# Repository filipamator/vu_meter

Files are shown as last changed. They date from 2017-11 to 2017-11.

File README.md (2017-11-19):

# vu_meter

This is a simple FPGA-based FFT audio signal analyzer. 
The project was made using Intel-Altera Quartus Prime 16.1 and implemented on DE2-115 board from Terasic.

I used an IP Core generated by Spiral Project, Carnegie Mellon University (http://www.spiral.net/hardware/dftgen.html).
The project is mostly written in VHDL with small exceptions  (SystemVerilog for ILI9341 TFT display, Verilog for I2S audio chip).

What does it do?
- An audio sample (1024 16-bit words from the left channel) is acquired using on-board I2S chip with 48 kHz (50 kHz in fact) sampling rate and 24 bits of vertical resolution. Only MSB 16 bits are used for calculations.
- A Hanning window function is applied to the samples stored in the on-chip memory. Integer samples are converted into the IEE-754 format, multiplied with a proper coefficient  and then converted again into a integer format.
- Spectrum is calculated using DFT IP Core from Spiral project with a spectral resolution around 25kHz/511 = 48.9 Hz per point/bin.
- A log10 is calculated for every spectral point after conversion to IEE-754 floating point format; here values are scaled to fit into TFT display: a full-scale sine wave from ADC will be plotted as 240-pixel vertical line at 320x240 TFT display.
- A proper bitmap is generated and stored in the frame buffer.

Comments on hardware:
- The input audio signal is echoed to headphone output
- KEY(0) is a global reset signal. Use it after uploading a compiled design.
- SW(1) selects log or linear scale. 
- Pressing KEY(1) will dump data over on-board UART

IMAGE ALT TEXT HERE (https://www.youtube.com/watch?v=xRw6NkzDQ_o)

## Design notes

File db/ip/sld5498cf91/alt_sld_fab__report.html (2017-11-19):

alt_sld_fab

2017.11.18.16:18:49 | Datasheet

Overview

Memory Map

## alt_sld_fab

alt_sld_fab v16.1

Parameters

DESIGN_HASH | 08e7e7f25aea91c42cac
NODE_COUNT | 1
MAX_WIDTH | 33
SETTINGS | {fabric sld dir agent mfr_code 110 type_code 0 version 6 instance 0 ir_width 10 psig 9b67919e}
CLOCKS | {id {} }
AGENTS
EP_INFOS | {hpath {sld_signaltap:auto_signaltap_0} }
MIRROR | 0
TOP_HUB | 1
COMPOSED_SETTINGS | {fabric sld dir agent mfr_code 110 type_code 0 version 6 instance 0 ir_width 10 bridge_agent 0 prefer_host {} }
DEVICE_FAMILY | CYCLONEIVE
AUTO_DEVICE | Unknown
AUTO_DEVICE_SPEEDGRADE | Unknown
deviceFamily | UNKNOWN
generateLegacySim | false

Software Assignments
(none)

## alt_sld_fab_presplit

altera_super_splitter v16.1

Parameters

MAX_WIDTH | 33
SEND_WIDTHS | 12
RECEIVE_WIDTHS | 33
deviceFamily | UNKNOWN
generateLegacySim | false

Software Assignments
(none)

## alt_sld_fab_splitter

altera_sld_splitter v16.1

alt_sld_fab_presplit | pass | alt_sld_fab_splitter
| nodes
alt_sld_fab_sldfabric | clock_0
| clock_0
| node_0
| node_0

Parameters

FRAGMENTS

{{name clock type clock dir end ports { {tck clk in 1 0} } } {name node type conduit dir end ports { {tms tms in 1 1} {tdi tdi in 1 2} {tdo tdo out 1 0} {ena ena in 1 3} {usr1 usr1 in 1 4} {clr clr in 1 5} {clrn clrn in 1 6} {jtag_state_tlr jtag_state_tlr in 1 7} {jtag_state_rti jtag_state_rti in 1 8} {jtag_state_sdrs jtag_state_sdrs in 1 9} {jtag_state_cdr jtag_state_cdr in 1 10} {jtag_state_sdr jtag_state_sdr in 1 11} {jtag_state_e1dr jtag_state_e1dr in 1 12} {jtag_state_pdr jtag_state_pdr in 1 13} {jtag_state_e2dr jtag_state_e2dr in 1 14} {jtag_state_udr jtag_state_udr in 1 15} {jtag_state_sirs jtag_state_sirs in 1 16} {jtag_state_cir jtag_state_cir in 1 17} {jtag_state_sir jtag_state_sir in 1 18} {jtag_state_e1ir jtag_state_e1ir in 1 19} {jtag_state_pir jtag_state_pir in 1 20} {jtag_state_e2ir jtag_state_e2ir in 1 21} {jtag_state_uir jtag_state_uir in 1 22} {ir_in ir_in in 10 23} {irq irq out 1 1} {ir_out ir_out out 10 2} } clock clock assign {debug.controlledBy {link_0} } moduleassign {debug.virtualInterface.link_0 {debug.endpointLink {fabric sld index 1} } } } }
EXAMPLE
ADD_INTERFACE_ASGN | 0
deviceFamily | UNKNOWN
generateLegacySim | false

Software Assignments
(none)

## alt_sld_fab_jtagpins

altera_jtag_pins_bridge v16.1

Parameters

deviceFamily | UNKNOWN
generateLegacySim | false

Software Assignments
(none)

## alt_sld_fab_sldfabric

altera_sld_jtag_hub v16.1

alt_sld_fab_jtagpins | clock | alt_sld_fab_sldfabric
| clock
| node
| node
| | | clock_0 | alt_sld_fab_splitter
| | | clock_0
| | | node_0
| | | node_0
| | | ident | alt_sld_fab_ident
| | | ident_0

Parameters

DEVICE_FAMILY | CYCLONEIVE
SETTINGS | {mfr_code 110 type_code 0 version 6 instance 0 ir_width 10 bridge_agent 0 prefer_host {} }
COUNT | 1
N_SEL_BITS | 1
N_NODE_IR_BITS | 10
NODE_INFO | 00110000000000000110111000000000
COMPILATION_MODE | 0
BROADCAST_FEATURE | 0
FORCE_IR_CAPTURE_FEATURE | 1
FORCE_PRE_1_4_FEATURE | 0
NEGEDGE_TDO_LATCH | 1
ENABLE_SOFT_CORE_CONTROLLER | 0
TOP_HUB | 1
CONN_INDEX | 0
deviceFamily | UNKNOWN
generateLegacySim | false

Software Assignments
(none)

## alt_sld_fab_ident

altera_connection_identification_hub v16.1

alt_sld_fab_sldfabric | ident | alt_sld_fab_ident
| ident_0

Parameters

DESIGN_HASH | 08e7e7f25aea91c42cac
COUNT | 1
SETTINGS | {width 4 latency 0}
deviceFamily | UNKNOWN
generateLegacySim | false

Software Assignments
(none)

generation took 0,01 seconds | rendering took 0,03 seconds

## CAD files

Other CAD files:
db/stp1_auto_stripped.stp
stp1_auto_stripped.stp
stp1.stp

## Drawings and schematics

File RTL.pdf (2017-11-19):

Date: November 19, 2017 | Project: vu_meter

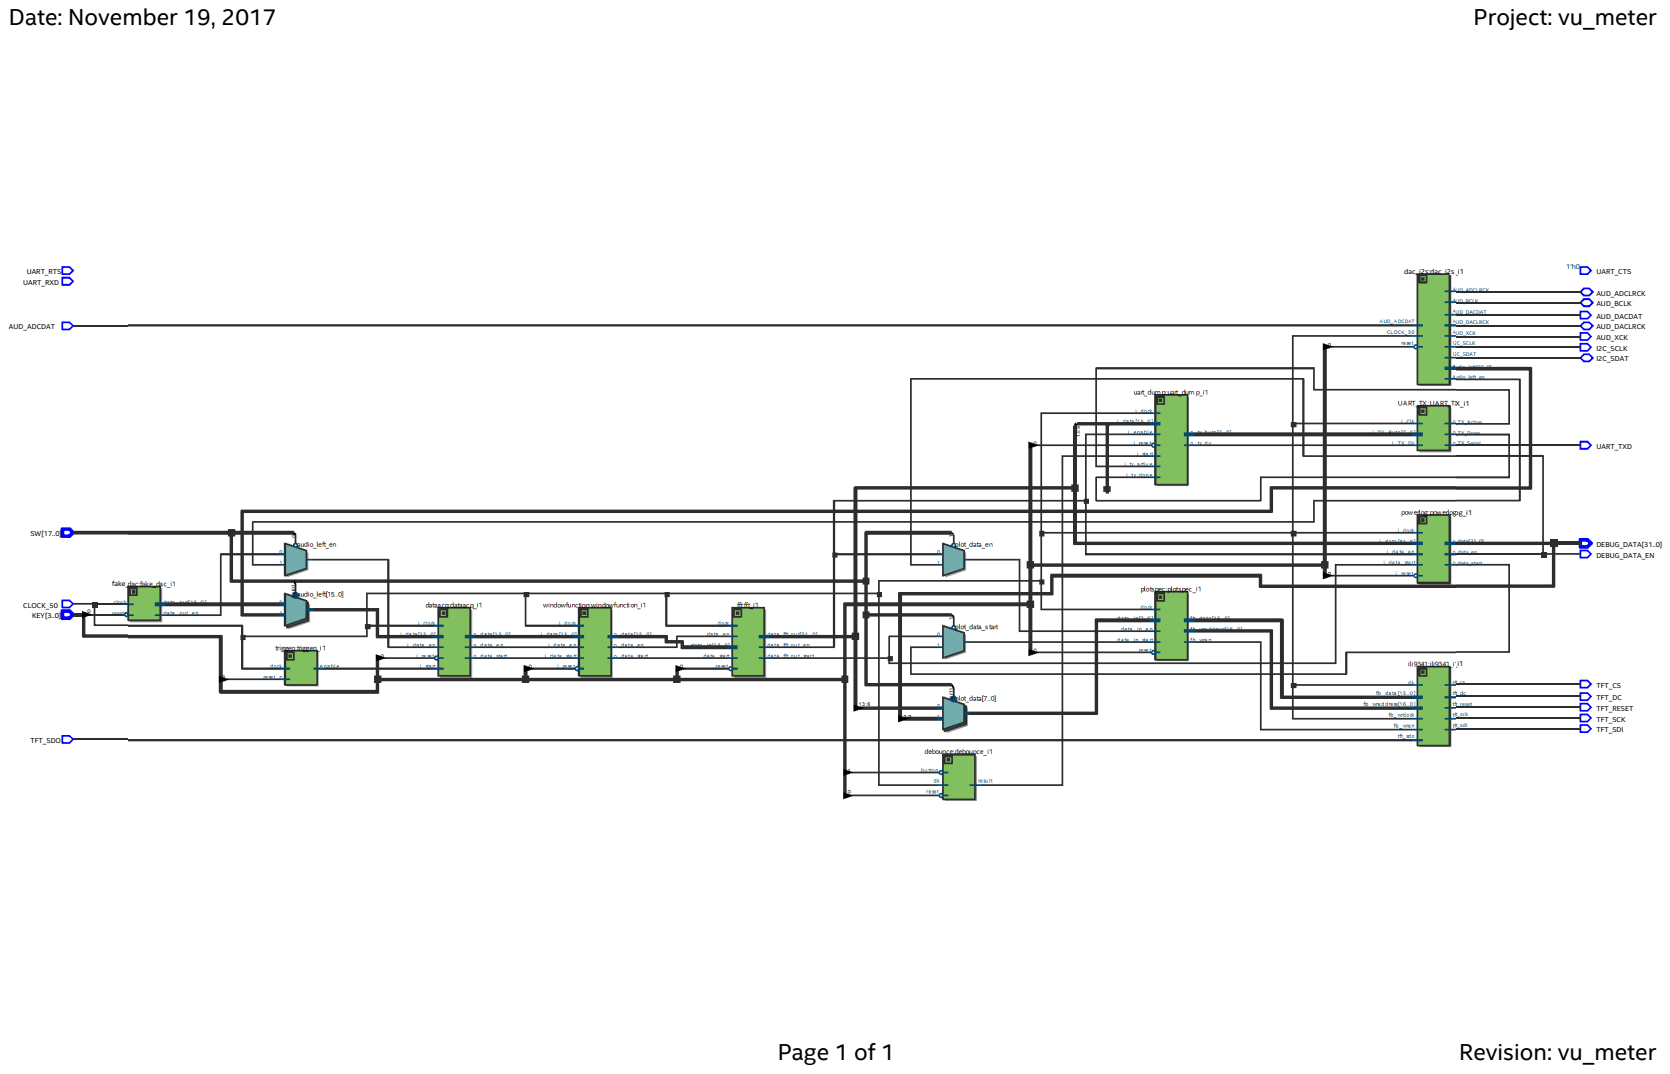
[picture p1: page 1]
Page 1 of 1; Revision: vu_meter; AUD_ADCLRCK; dac_i2s:dac_i2s_i1; AUD_BCLK; AUD_DACDAT; AUD_DACLRCK; AUD_XCK; I2C_SCLK; I2C_SDAT; audio_left_en; audio_left[15..0]; AUD_DACLRCK AUD_XCK; I2C_SCLK I2C_SDAT; AUD_ADCDAT; o_TX_Active; o_TX_Done; o_TX_Serial; UART_TXD; DEBUG_DATA_EN; o_data_en; o_data_start; o_data[31..0]; DEBUG_DATA[31..0]; fake_dac:fake_dac_i1; clock; reset; CLOCK_50 KEY[3..0]; TFT_CS; TFT_DC; tft_cs; tft_dc; tft_reset; tft_sck; tft_sdi; TFT_RESET; TFT_SDO; TFT_SCK TFT_SDI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

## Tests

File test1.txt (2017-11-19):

0 0
1 0
2 0
3 0
4 0
5 0
6 0
7 0
8 0
9 0
10 0
11 0
12 0
13 0
14 0
15 0
16 0
17 0
18 0
19 0
20 0
21 0
22 0
23 0
24 0
25 0
26 0
27 0
28 0
29 0
30 0
31 0
32 0
33 0
34 0
35 0
36 0
37 0
38 0
39 0
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

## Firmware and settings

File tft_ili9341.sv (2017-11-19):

/** Simple frame-buffer based driver for the ILI9341 TFT module */
module tft_ili9341(
		input clk,
		input tft_sdo, 
		output wire tft_sck, 
		output wire tft_sdi, 
		output wire tft_dc, 
		output reg tft_reset, 
		output wire tft_cs,
		input[15:0] framebufferData, 
		output wire framebufferClk, 
		output  px_count, 
		output wire fb_start
	);
	
	parameter INPUT_CLK_MHZ = 120; /* recommended */
	
	// Initial assignments
	initial tft_reset = 1'b1;

	// Assign pins and modules
	reg[8:0] spiData; 
	reg spiDataSet = 1'b0;
	wire spiIdle;
	
	reg frameBufferLowNibble = 1'b1;
	assign framebufferClk = !frameBufferLowNibble;
	assign px_count = PixelCounter;
	
	
	tft_ili9341_spi spi(
		.spiClk(clk), 
		.data(spiData), 
		.dataAvailable(spiDataSet),
		.tft_sck(tft_sck), 
		.tft_sdi(tft_sdi), 
		.tft_dc(tft_dc), 
		.tft_cs(tft_cs),
		.idle(spiIdle)
		);
	
	// Init Sequence Data (based upon https://github.com/notro/fbtft/blob/master/fb_ili9341.c)
	localparam INIT_SEQ_LEN = 52;
	reg[5:0] initSeqCounter = 6'b0;
	reg[8:0] INIT_SEQ [0:INIT_SEQ_LEN-1] = '{
		// Turn off Display
		{1'b0, 8'h28},
		// Init (??)
		{1'b0, 8'hCF}, {1'b1, 8'h00}, {1'b1, 8'h83}, {1'b1, 8'h30}, 
		{1'b0, 8'hED}, {1'b1, 8'h64}, {1'b1, 8'h03}, {1'b1, 8'h12}, {1'b1, 8'h81},
		{1'b0, 8'hE8}, {1'b1, 8'h85}, {1'b1, 8'h01}, {1'b1, 8'h79}, 
		{1'b0, 8'hCB}, {1'b1, 8'h39}, {1'b1, 8'h2C}, {1'b1, 8'h00}, {1'b1, 8'h34}, {1'b1, 8'h02},
		{1'b0, 8'hF7}, {1'b1, 8'h20},
		{1'b0, 8'hEA}, {1'b1, 8'h00}, {1'b1, 8'h00},
		// Power Control
		{1'b0, 8'hC0}, {1'b1, 8'h26},
		{1'b0, 8'hC1}, {1'b1, 8'h11},
		// VCOM
		{1'b0, 8'hC5}, {1'b1, 8'h35}, {1'b1, 8'h3E},
		{1'b0, 8'hC7}, {1'b1, 8'hBE},
		// Memory Access Control
		{1'b0, 8'h3A}, {1'b1, 8'h55},
		// Frame Rate
		{1'b0, 8'hB1}, {1'b1, 8'h00}, {1'b1, 8'h1B},
		// Gamma
		{1'b0, 8'h26}, {1'b1, 8'h01},
		// Brightness
		{1'b0, 8'h51}, {1'b1, 8'hFF},
		// Display
		{1'b0, 8'hB7}, {1'b1, 8'h07},
		{1'b0, 8'hB6}, {1'b1, 8'h0A}, {1'b1, 8'h82}, {1'b1, 8'h27}, {1'b1, 8'h00},
		{1'b0, 8'h29}, // Enable Display
		{1'b0, 8'h2C} // Start  Memory-Write
	};
	
	
	// state machine with delay + idle support (used for initialization)
	
	reg[23:0] remainingDelayTicks = 24'b0;
	
	reg[16:0] PixelCounter = 17'b0;

	
	enum logic[2:0] { START, HOLD_RESET, WAIT_FOR_POWERUP, SEND_INIT_SEQ, LOOP} state = START;
	always @ (posedge clk) begin
	
		// clear data flag first
		spiDataSet <= 1'b0; 
		
		// always decrement delay ticks
		if (remainingDelayTicks > 0) begin
			remainingDelayTicks <= remainingDelayTicks - 1'b1;
		end
		else if (spiIdle && !spiDataSet) begin
			// advance state machine to next state, but only do this if we
			// didn't just clock in the last byte (since idle is not yet updated)
			case (state)
				// initialize all pins in START mode; reset the LCD
				START: begin
					tft_reset <= 1'b0;
					remainingDelayTicks <= 24'(INPUT_CLK_MHZ * 10); // min: 10us
					state <= HOLD_RESET;
				end
				
				// wait for RESET to kick in; then release pin & wait for power up
				HOLD_RESET: begin
					tft_reset <= 1'b1; // release pin
					remainingDelayTicks <= 24'(INPUT_CLK_MHZ * 120000); // min: 120ms
					state <= WAIT_FOR_POWERUP;
					frameBufferLowNibble <= 1'b0; // request first pixel
				end
				
				// if power up is completed -> sw reset
				WAIT_FOR_POWERUP: begin
					spiData <= {1'b0, 8'h11}; // take out of sleep mode
					spiDataSet <= 1'b1; 
					remainingDelayTicks <= 24'(INPUT_CLK_MHZ * 5000); // min: 5ms
					state <= SEND_INIT_SEQ;
					frameBufferLowNibble <= 1'b1;
					PixelCounter <= PixelCounter + 1'b1;
				end
				
				// setup the LCD by sending the init sequence
				SEND_INIT_SEQ: begin
					if (initSeqCounter < INIT_SEQ_LEN) begin
						spiData <= INIT_SEQ[initSeqCounter];
						spiDataSet <= 1'b1;
						initSeqCounter <= initSeqCounter + 1'b1;
					end else begin
						state <= LOOP;
						remainingDelayTicks <= 24'(INPUT_CLK_MHZ * 10000); // min: 10ms
					end
				end
				
				// frame buffer loop
				default: begin
					spiData <= !frameBufferLowNibble ? {1'b1, framebufferData[15:8]} :{1'b1, framebufferData[7:0]};
					spiDataSet <= 1'b1;
					frameBufferLowNibble <= !frameBufferLowNibble;
					
					if (frameBufferLowNibble)
					begin
						PixelCounter <= (PixelCounter + 1'b1) % 17'(320*240);
					end

					if (PixelCounter == 76799)
					begin
						fb_start <= 1'b1;
					end
					else
					begin
						fb_start <= 1'b0;
					end
					
					
				end
			endcase
		end
	end
		
	
endmodule

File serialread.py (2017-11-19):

import serial
import time
ser = serial.Serial('COM5', 4*115200, timeout=1)

buffer = bytearray([])
sample = bytearray([])
counter = 0

def twos_comp(val, bits):
    """compute the 2's complement of int value val"""
    if (val & (1 << (bits - 1))) != 0: # if sign bit is set e.g., 8bit: 128-255
        val = val - (1 << bits)        # compute negative value
    return val 

ser.reset_input_buffer()

while counter<2048:
  bufflen = ser.in_waiting
  if bufflen > 0:
    buffer =  ser.read(bufflen)
    sample = sample + buffer
    counter = counter + len(buffer)
    time.sleep(0.05)


#print(len(buffer))
size = len(sample)/2
for x in range(0, int(size) ):
  value = 256*sample[2*x] + sample[2*x+1]
  value = twos_comp(value,16)
  print(str(x) + " " + str(value))



#print(buffer[0])
  
